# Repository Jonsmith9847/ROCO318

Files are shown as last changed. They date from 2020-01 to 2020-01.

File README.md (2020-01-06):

# ROS Pan Tilt Camera

This documentation covers all the required information, equipment and software for the ROS Pan Tilt Camera system.

## Getting Started

These instructions will get you a copy of the project up and running on your local machine for development and testing purposes. The instructions will also guide you through the hardware use and construction.

### Prerequisites

Prior to installation the following software components are required:
 - Operating System: **[Ubuntu 16.04 LTS](http://releases.ubuntu.com/16.04/)**
 - ROS Version: **[ROS Kinetic Kame](http://wiki.ros.org/kinetic)**
 
The following hardware components are also required:
 - Camera: **[Logitech C920 Web Camera](https://www.logitech.com/en-gb/product/hd-pro-webcam-c920)**
 - Motors: **[Dynamixel AX-12](https://www.trossenrobotics.com/dynamixel-ax-12-robot-actuator.aspx) (x2)**
 - Dynamixel Controller: **[USB2Dynamixel Adapter](https://www.trossenrobotics.com/robotis-bioloid-usb2dynamixel.aspx)** 
 - Dynamixel 3 Pin Cables: **[Dynamixel Cable](https://www.trossenrobotics.com/p/200mm-3-pin-dynamixel-compatible-cables-10-pack) (x3)**
 -  3D Printed Parts:
	 - Base Part: **[STL Model](https://github.com/Jonsmith9847/ROCO318/blob/master/CAD%20Files/Base.stl)**
	 - Tilt Bracket: **[STL Model](https://github.com/Jonsmith9847/ROCO318/blob/master/CAD%20Files/Joint.stl)**
	 - Camera Mount: **[STL Model](https://github.com/Jonsmith9847/ROCO318/blob/master/CAD%20Files/CamMount.stl)**

### Construction

 1.  Using screws, mount a [Dynamixel AX-12](https://www.trossenrobotics.com/dynamixel-ax-12-robot-actuator.aspx) motor into the [Base Part](https://github.com/Jonsmith9847/ROCO318/blob/master/CAD%20Files/Base.stl). 
	
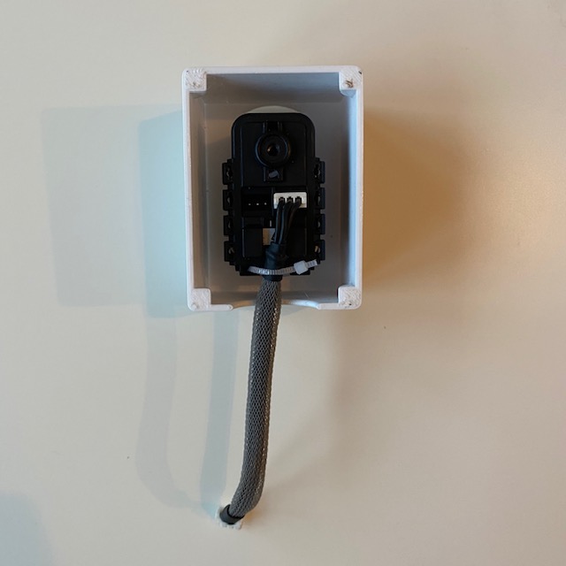
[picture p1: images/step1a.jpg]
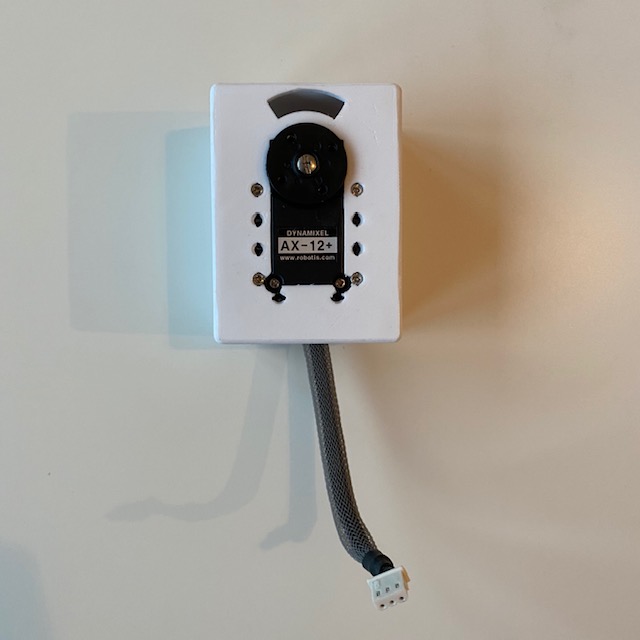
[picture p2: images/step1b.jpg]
   

 2. Using screws, connect the [Tilt Bracket](https://github.com/Jonsmith9847/ROCO318/blob/master/CAD%20Files/Joint.stl) to the top of the Base Motor. 
	
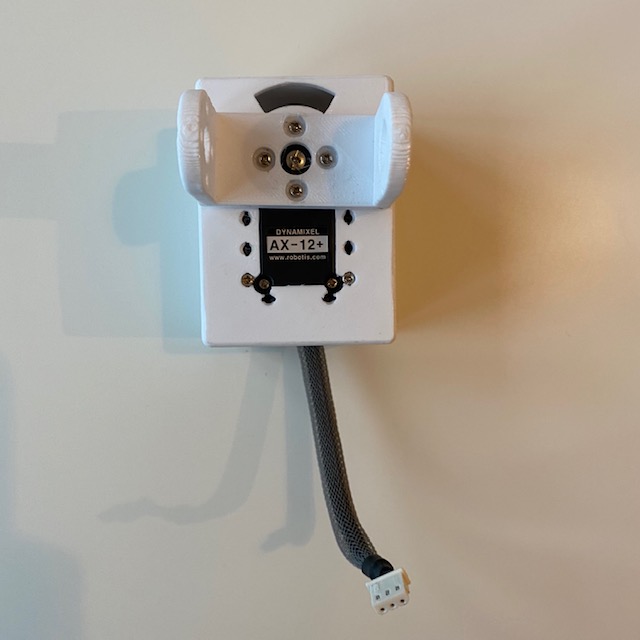
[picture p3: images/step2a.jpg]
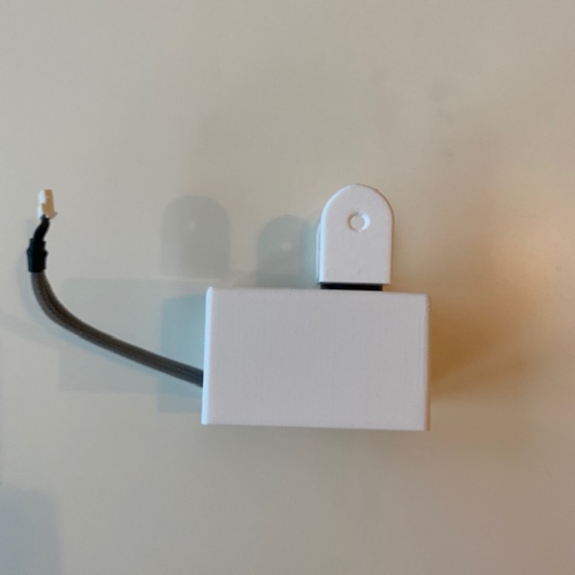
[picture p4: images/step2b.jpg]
   

 3. Using screws, connect the final [Dynamixel AX-12](https://www.trossenrobotics.com/dynamixel-ax-12-robot-actuator.aspx) to the [Tilt Bracket](https://github.com/Jonsmith9847/ROCO318/blob/master/CAD%20Files/Joint.stl). Ensure that the non-driven side of the motor is free to rotate.    
   
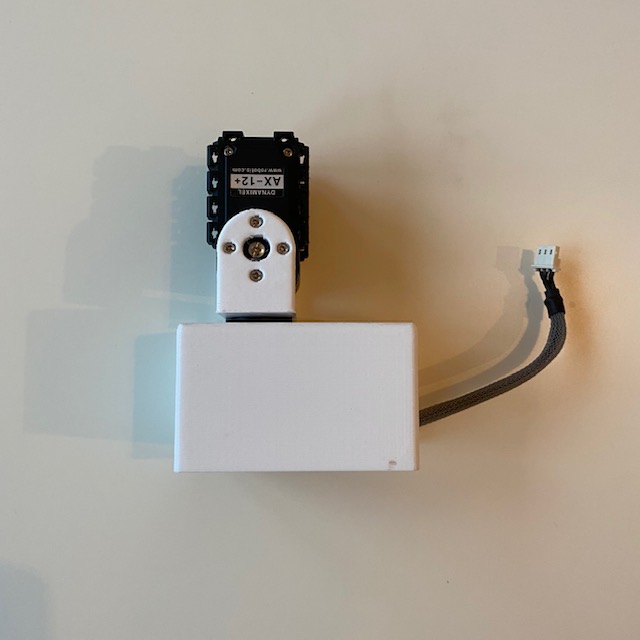
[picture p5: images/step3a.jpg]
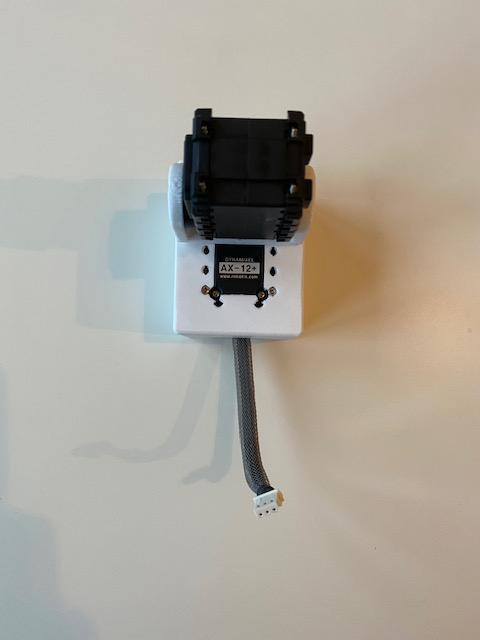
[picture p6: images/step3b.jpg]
   
   
 4. Screw the [Camera Mount](https://github.com/Jonsmith9847/ROCO318/blob/master/CAD%20Files/CamMount.stl) to the top of the Tilt Motor. 

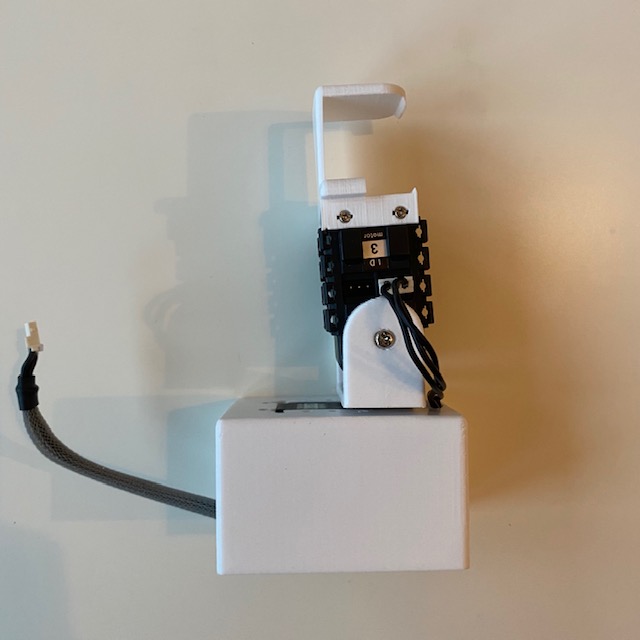
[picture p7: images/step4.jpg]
  
 
 6. Feed a [Dynamixel Cable](https://www.trossenrobotics.com/p/200mm-3-pin-dynamixel-compatible-cables-10-pack) through the cable managment hole in the base and connect the two motors together.
 
 7. Add an additional [Dynamixel Cable](https://www.trossenrobotics.com/p/200mm-3-pin-dynamixel-compatible-cables-10-pack) to the base motor and secure with a single zip tie.
 
 8. Slot the [Logitech C920 Web Camera](https://www.logitech.com/en-gb/product/hd-pro-webcam-c920) into the bracket and use double sided tape to secure if required.
 
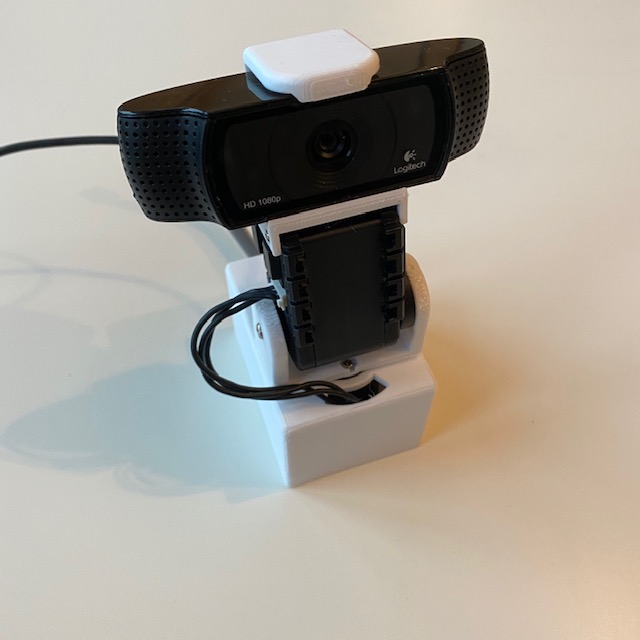
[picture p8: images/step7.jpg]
  
 
 9. Connect the remaining electronics as show, ensuring that the [USB2Dynamixel Adapter](https://www.trossenrobotics.com/robotis-bioloid-usb2dynamixel.aspx) switch is set to TTL mode.

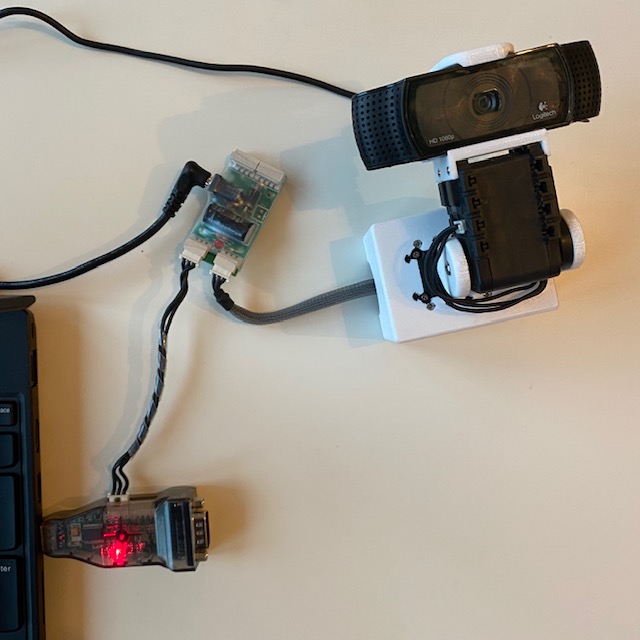
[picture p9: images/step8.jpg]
  

## Installing the project

### Clone the files

 1. Download the repository:
```git clone https://github.com/Jonsmith9847/ROCO318.git```
2. Navigate to the workspace:
```cd catkin_ws/```
3. Source the bash file:
```source devel/setup.bash```
4. Build the project:
```catkin_make```

### Webcam Installation
 1. Start ROS in a new terminal:
```roscore```
2. Identify the webcam you want to use:
```ls /dev/video*```
3. Edit /catkin_ws/src/usb_cam/launch/usb_cam-test.launch if necessary to select the correct camera.
	i.e. edit video device "/dev/video1" to "/dev/video0"
4. Navigate to the src folder:
```cd catkin_ws/src```
5. Launch the usb cam node:
```roslaunch usb_cam/launch/usb_cam-test.launch```
6. Start RVIZ in a new terminal:
```rviz```
7. In RVIZ add a new Image view. 
Add > Image > Ok
![RVIZcam1.png](https://github.com/Jonsmith9847/ROCO318/blob/master/images/RVIZcam1.png?raw=true)
9. Set Image Topic to /usb_cam/image_raw
![RVIZcam2.png](https://github.com/Jonsmith9847/ROCO318/blob/master/images/RVIZcam2.png?raw=true)

### Motor controller Installation
 1. Start ROS in a new terminal if not already started:
```roscore```
2. Navigate to the src folder:
```cd catkin_ws/src/```
3. Launch the controller manager:
```roslaunch dynamixel_motors/src/controller_manager.launch```
4. Launch the joint controllers:
```roslaunch dynamixel_motors/src/joint_controller.launch```

Moving the pan motor:
```rostopic pub -1 /pan_controller/command std_msgs/Float64 -- 2.61```
(Min: 0 - Mid: 2.6 - Max: 5.2)

Moving the tilt motor:
```rostopic pub -1 /tilt_controller/command std_msgs/Float64 -- 2.61```
(Min: 1.0 - Mid: 2.6 - Max: 4.2)

## CAD Models

The CAD Model for the project was produced using [Fusion360](https://www.autodesk.co.uk/products/fusion-360/overview#banner]). The final design includes the following models:
**Dynamixel AX-12 [https://www.trossenrobotics.com/dynamixel-ax-12-robot-actuator.aspx]**
**Logitech C920 Webcam [[https://grabcad.com/library/logitech-hd-pro-webcam-c920-1](https://grabcad.com/library/logitech-hd-pro-webcam-c920-1)]**

<img src="https://github.com/Jonsmith9847/ROCO318/blob/master/Renders/Front.jpg?raw=true" width="300" height="300"><img src="https://github.com/Jonsmith9847/ROCO318/blob/master/Renders/Side.jpg?raw=true" width="300" height="300"><img src="https://github.com/Jonsmith9847/ROCO318/blob/master/Renders/IsometricFront.jpg?raw=true" width="300" height="300"><img src="https://github.com/Jonsmith9847/ROCO318/blob/master/Renders/IsometricRear.jpg?raw=true" width="300" height="300"><img src="https://github.com/Jonsmith9847/ROCO318/blob/master/Renders/Top.jpg?raw=true" width="300" height="300"><img src="https://github.com/Jonsmith9847/ROCO318/blob/master/Renders/Bottom.jpg?raw=true" width="300" height="300">

STL Files and Fusion 360 files can be found in the following location:
[https://github.com/Jonsmith9847/ROCO318/tree/master/CAD%20Files](https://github.com/Jonsmith9847/ROCO318/tree/master/CAD%20Files)

## DEMO VIDEO

Demo Video: **[YOUTUBE](https://www.youtube.com/embed/bqHWkLoYdAc)**

This demo video shows both the motors and webcam operating.
The pan and tilt motors are controlled using commands from ROS. 
The webcam feed is shown live in RVIZ.

## Authors

* **Jonathan Smith** - *Project* - [Jonsmith9847](https://github.com/Jonsmith9847)

## Acknowledgments

This project contains the following packages:
* **[dynamixel_controllers](http://wiki.ros.org/dynamixel_controllers)**
	Authors: Antons Rebguns, Cody Jorgensen, Cara Slutter
	
* **[usb_cam](http://wiki.ros.org/usb_cam)** 
	* Author: Benjamin Pitzer

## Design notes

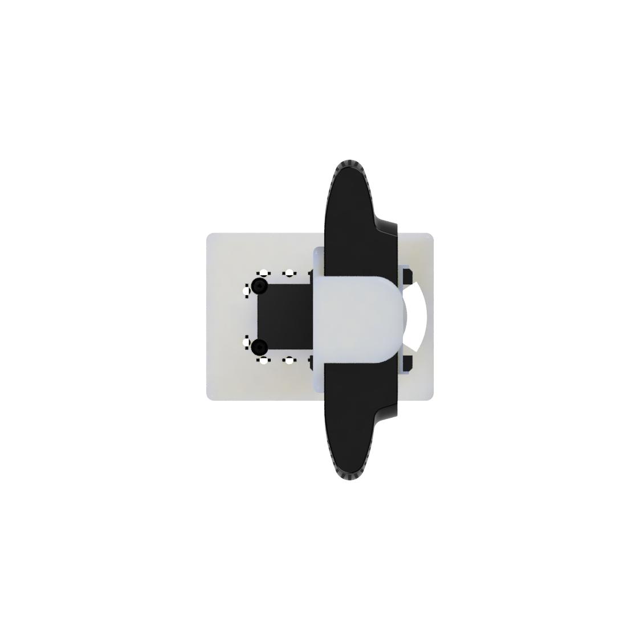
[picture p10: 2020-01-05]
Renders/Top.jpg

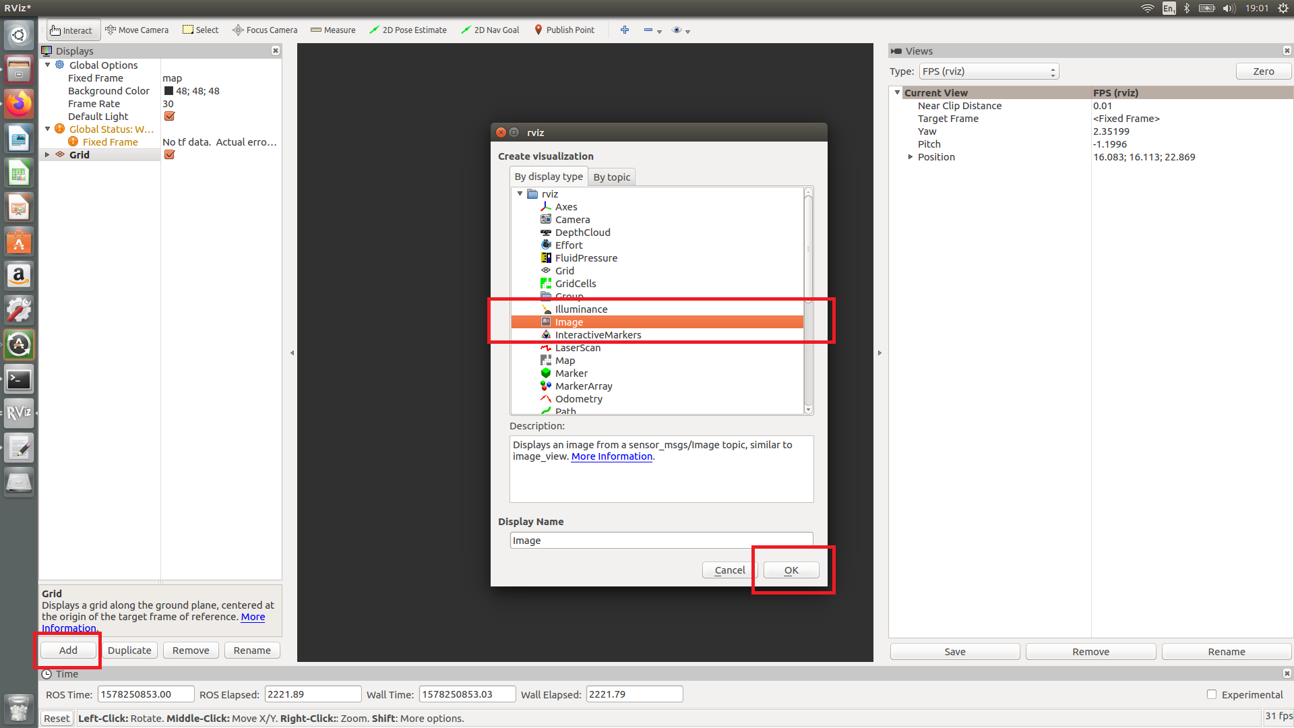
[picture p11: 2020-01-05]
images/RVIZcam1.png

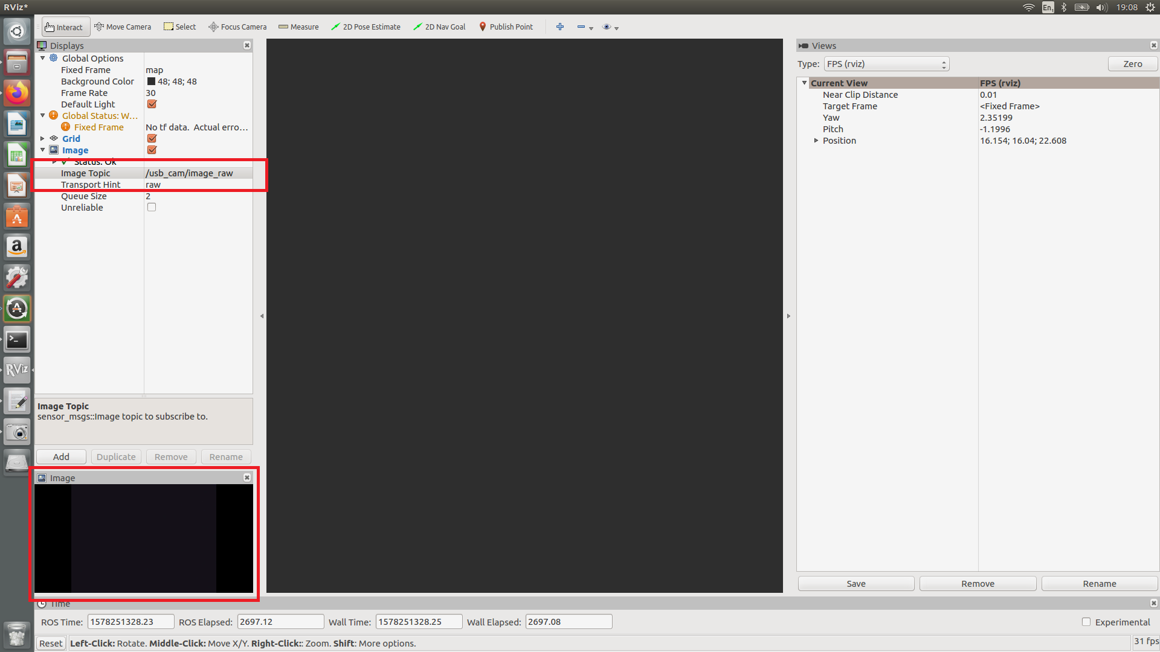
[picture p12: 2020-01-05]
images/RVIZcam2.png

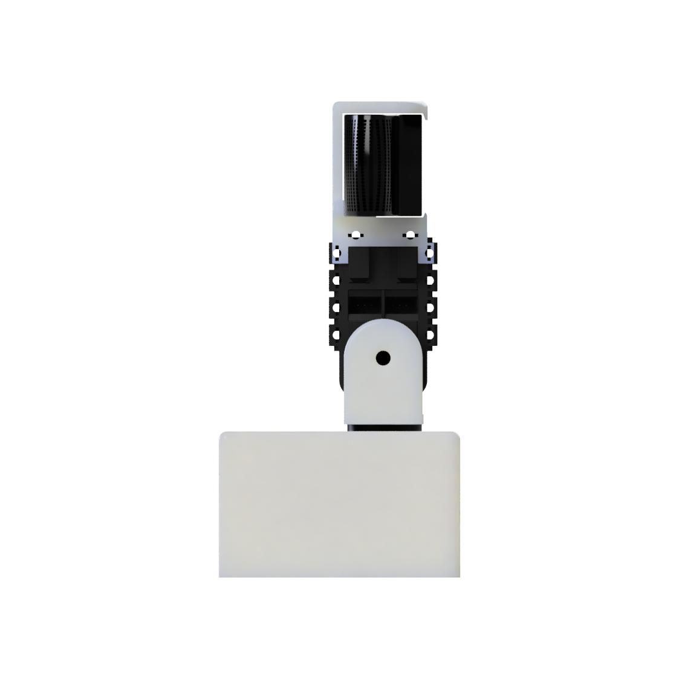
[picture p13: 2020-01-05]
Renders/Side.jpg

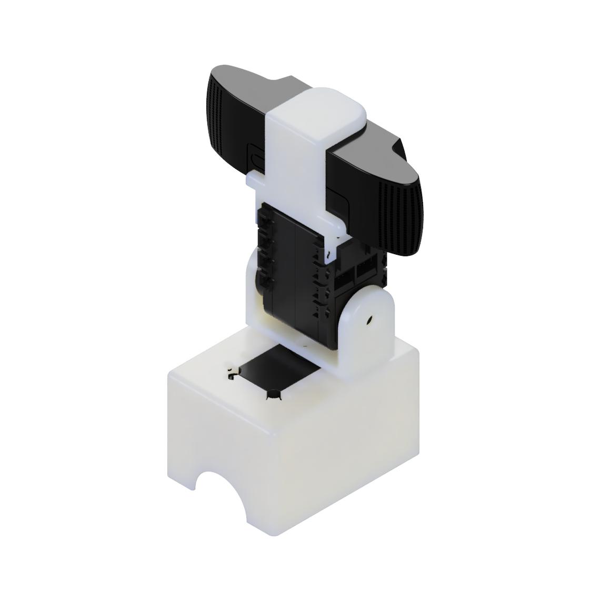
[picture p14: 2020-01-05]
Renders/IsometricRear.jpg

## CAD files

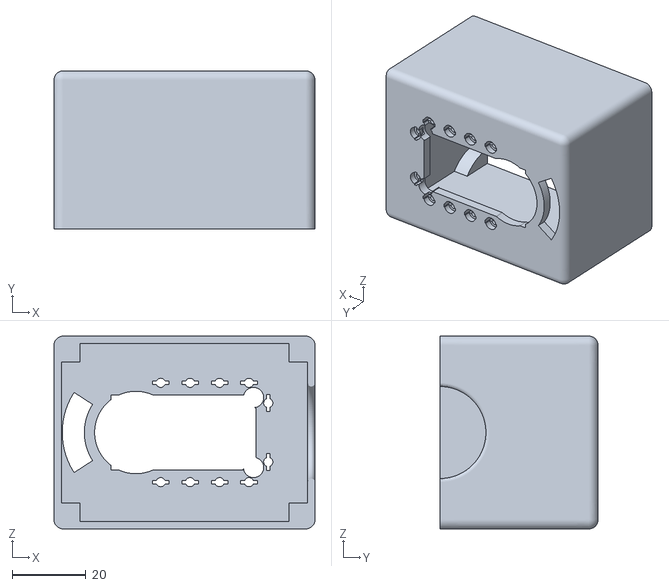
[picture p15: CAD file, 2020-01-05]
CAD Files/Base.stl
71.0 x 43.0 x 52.4

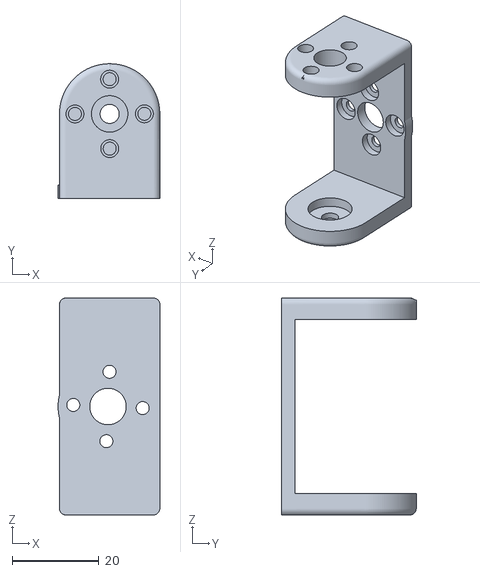
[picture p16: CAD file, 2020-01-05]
CAD Files/Joint.stl
23.5 x 31.0 x 50.0

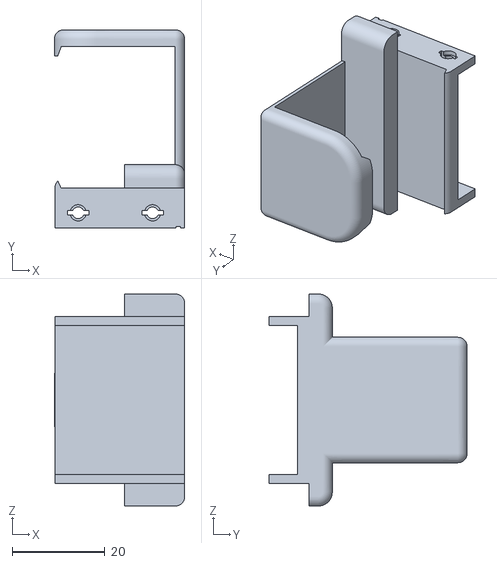
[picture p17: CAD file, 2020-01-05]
CAD Files/CamMount.stl
28.1 x 42.7 x 45.6

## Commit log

2020-01-05 Added CAD Files + Renders
    [Base.stl, CamMount.stl, Joint.stl]
2020-01-05 Updated assembly Instructions in Readme
2020-01-05 Added new packages
    [08-macroed.urdf.xacro, tilt.urdf]
2020-01-05 Added packages
    [64_joint_robot.urdf, mimic_chain.urdf, mimic_cycle.urdf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]
2020-01-05 Added controller manager
    [08-macroed.urdf.xacro, 64_joint_robot.urdf, mimic_chain.urdf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]
2020-01-06 Updated motor controller
